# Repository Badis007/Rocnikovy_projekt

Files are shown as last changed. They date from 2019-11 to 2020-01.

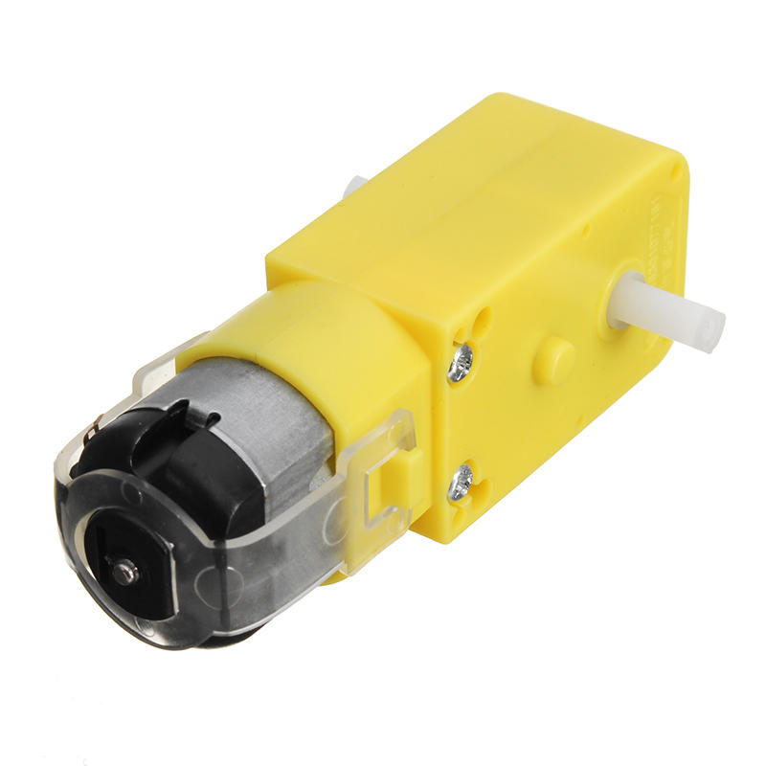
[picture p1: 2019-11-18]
Soucastky/3ec6e260-2719-4dba-aa2e-fc9864818fe9.jpeg

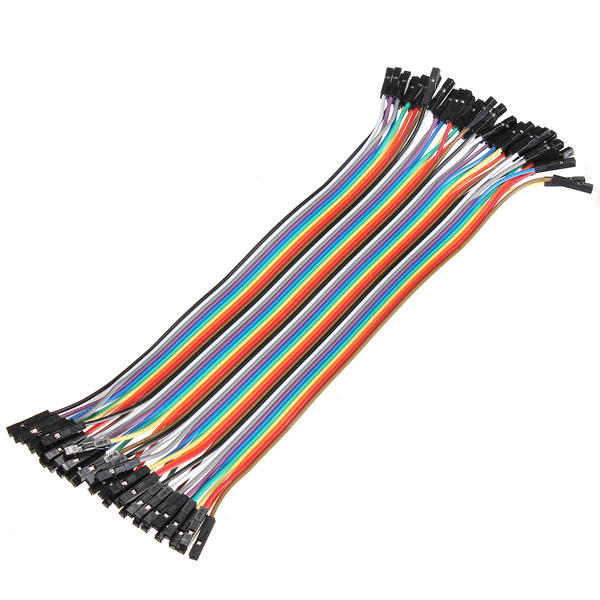
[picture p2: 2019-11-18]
Soucastky/SKU067911h.jpeg

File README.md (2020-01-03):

# Ročníkový projekt - autíčko ovládané přes wifi

Inspirace - https://www.youtube.com/watch?v=mJEftoeSBOU

tohle -> https://www.youtube.com/watch?v=gU7vlhU1HvU

# Harmonogram:
- [x] Září - objednávka součástek

- [x] Říjen - Pájení motorů, stavba podvozku

- [x] Listopad - aplikace, připojení na wifi, zapojení součástek na podvozek.

- [x] Prosinec - zpracování dokumentace.

- [ ] Leden - dokončení a doladění projektu.

# Stav projektu:
- Objednaný podvozek byl moc malý, náhrada dřevěným výřezem. 
- Sestavení autíčka doma bez podvozku, následné rozebrání pro přenos do školy, o víkendu následné sestavení na nový podvozek a nalepení     tavící pistolí. 
- vyřešení připojení na wifi.
- Sestavení celého auta do funkčního stavu.
- Úspěšně otestováno v přiloženém videu na mém githubu ve složce "stavba projektu". 
- V následujících dnech doupravím zapojení auta k lepší vizuální podobě a optimalizuju kód.
- Optimalizovaný kód, z aplikace uložena hodnota 1-5 pro každou funkci zvlášť do stringu, string se v ESP převede na int, poté je poslán      do switche pro splnění podmínek, následně vyvolána určitá funkce podle směru zmáčknutí tlačítka v aplikaci.
- Kabely FM to FM nahrazeny za napájené spoje, přidán vypínač pro lepší přehlednost a vyhnutí se stálemu vytahování baterek z holderu. 
- Kabely motorů vylepšeny a nahrazeny.
- Optimalizovaný kód auta.
- Doladění aplikace, jednoduchž design.
------------------------------------------
- Dokumentace, napájet kolo z5, přilepit motor, test, prezentace

# Potřebné součástky
- 4x motorek + kolečka
- motor driver
- ESP8266
- battery holder 
- přepínač

# Odkazy: 
- ESP8266 https://navody.arduino-shop.cz/navody-k-produktum/esp8266-vyvojova-deska-wemos-d1.html
- L298N https://robotelektro.cz/moduly-sestavene?product_id=81
- Motor s převodovkou https://www.hwkitchen.cz/motor-s-prevodovkou-pro-arduino-robota/

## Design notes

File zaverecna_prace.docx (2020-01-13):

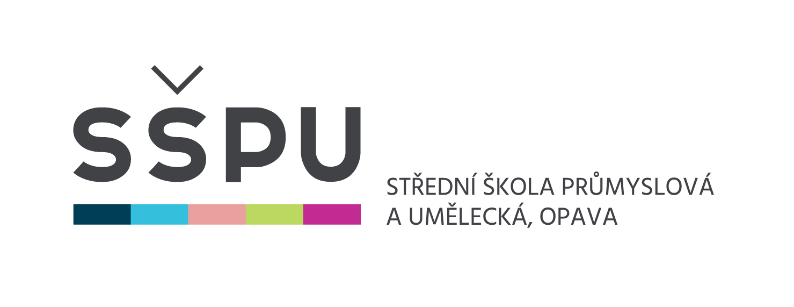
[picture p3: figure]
Logo__SSPU_2016_Barva

Závěrečná studijní práce

dokumentace

Auto na dálkové ovládání

Lukáš Baďura

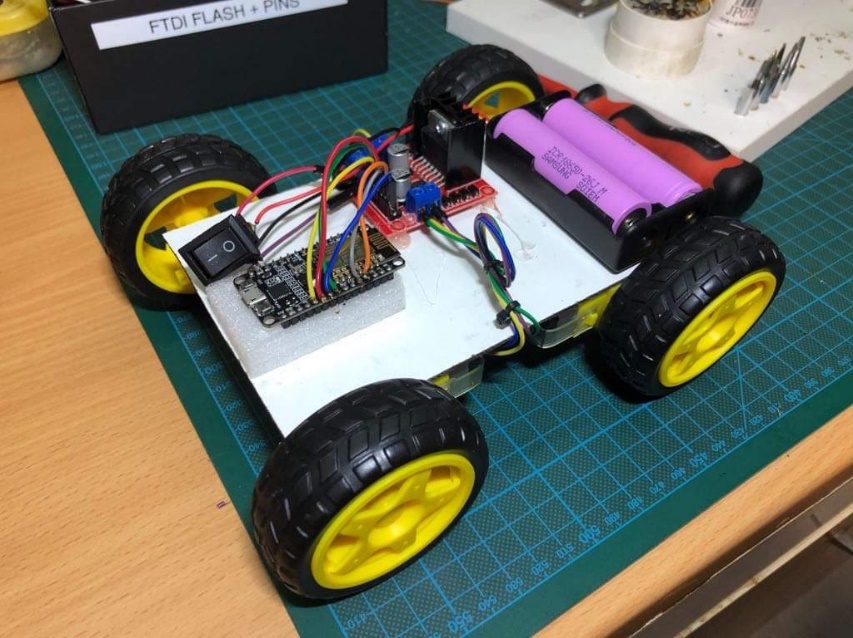
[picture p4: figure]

Obor: | 18-20-M/01 INFORMAČNÍ TECHNOLOGIE se zaměřením na počítačové sítě a programování
Třída: Školní rok: | IT4 2019/2020

#### Poděkování

Děkuji panu učiteli Ing. Petru Grussmannovi za užitečné rady, vylepšení a konzultaci mého projektu. Mým spolužákům za pomoc a řešení společných problémů.

Prohlašuji, že jsem závěrečnou práci vypracoval samostatně a uvedl veškeré použité
informační zdroje.

Souhlasím, aby tato studijní práce byla použita k výukovým účelům na Střední průmyslové
a umělecké škole v Opavě, Praskova 399/8.

V Opavě 31. 12. 2019

podpis autora práce

ANOTACE

Cílem projektu bylo sestavení auta na dálkové ovládání z mobilní aplikace v Android Studiu pomocí WiFi. Hardwarovou část tvoří vývojová deska NodeMcu s čipem ESP8266. Zařízení za pomoci již zmíněného ESP8266 a modulu L298N řídí čtyři převodové motory. Mobilní aplikace posílá ESP hodnoty, pokud jsou vyhodnoceny jako „pravda“ je spuštěna příslušná funkce pro pohyb auta. Softwarová část auta je řešena v jazyce Arduino, který je kombinací jazyků C a C++.

Goal of the project was build a remote controlling car with mobile application in Android Studio which uses WiFi to communicate. Hardware part of the project is development board with chip ESP8266. Project uses ESP8266 and L298N module to control 4 geared motors. Mobile application sends values to ESP. If is value evaluated as „true“ the function for car direction controll is launched. Software part of the project is wrote in Arduino language which is the combination of C and C++ languages.

Klíčová slova

WiFi; dálkové ovládání; NodeMcu; Arduino; převodové motory; mobilní aplikace; motorový modul

# OBSAH

# Úvod

Tento projekt jsem si vybral, aby mi závěrečná práce nebyla nejen znalostním přínosem, ale i zábavou.

Auto na dálkové ovládání mě zaujalo a vybral jsem si ho, po shlédnutí mnoha videí spojených s roboty a auty ovládanými přes WiFi.

Projekt má dvě hlavní části. Ručně sestavené auto na dálkové ovládání a mobilní aplikaci. Tyto dvě části vzájemně komunikují pomocí již zmíněné WiFi. Ve své dokumentaci popisuji použité technologie a principy fungování.

# 1 SESTAVENÍ AUTA

Po zakoupení součástek jsem začal se zapojením jednoho motorku s kolem do jednoduchého obvodu s ESP8266, H-můstkem L298N a externím napájením.

Nahrál jsem do obvodu jednoduchý program pro roztočení kola s motorkem vpřed. Po úspěšném testu součástek jsem se rozhodl na každý motorek s kolem připájet dva drátky a následně přilepit tavnou pistolí ke spodní části podvozku.

Dále jsem na vrchní část podvozku nalepil postupně ESP8266, H-můstek L298N a externí zdroj napájení. Motorky jsem pomocí připájených drátků zapojil do výstupních konektorů H-můstku. H-můstek jsem propojil kabely s ESP a následně zapojil externí napájení. Po zapojení obvodů již na podvozku jsem přešel k nahrání jednoduchého kódu pro pohyb auta vpřed a vzad.

Po úspěšném otestování jsem přešel k finálnímu doladění celého obvodu. Drátky z H-můstku jsem připájel na piny ESP pro bezpečnější funkčnost při jízdě, k externímu napájení jsem přidal vypínač pro pohodlnější zapnutí a drátky vedoucí z motorků jsem lépe spojil k sobě, pro lepší stabilitu a funkčnost auta. Po uspokojivém zapojení všech součástek jsem přešel k řešení problematiky softwarové části.

# 2 Využité technologie

## 2.1 Hardware

### 2.1.1 Seznam součástek

### Vývojová deska NodeMcu

### H-můstek pro krokový motor L298N

### Dvě 18650 Li-Ion Baterie

### Bateriový box

### Propojovací kabely F-F

### Propojovací kabely M-M

### Čtyři kola s převodovými motory

### Přepínač 6A 250VAC

### 2.1.2 NodeMcu

Základ projektu tvoří vývojová deska NodeMcu. Deska je založena na čipu ESP8266 od společnosti Expressif. Hardware je založen na modulu ESP-12E.

Deska obsahuje 11 digitálních I/O pinů a 1 analogový vstup. Programu je k dispozici paměť o velikosti 128kB. NodeMcu na rozdíl od ostatních součástek pracuje s napětím 3,3V.

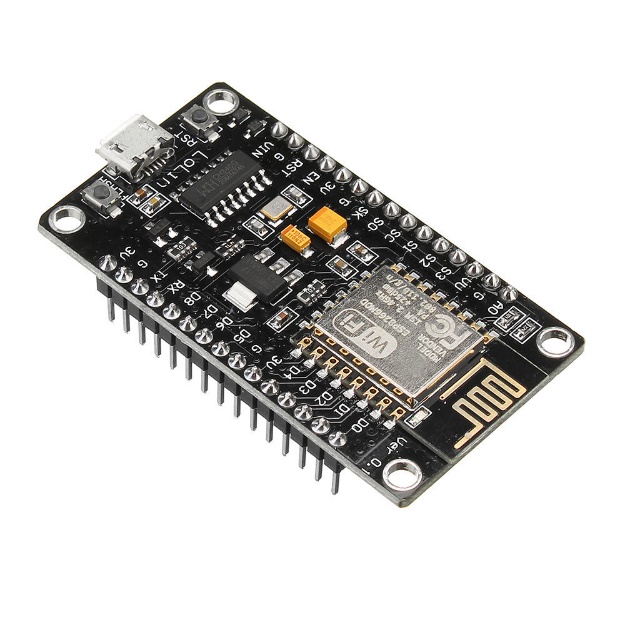
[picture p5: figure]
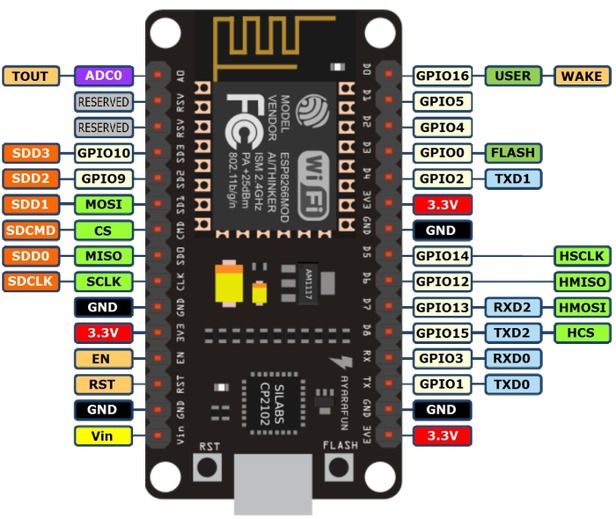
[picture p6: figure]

### 2.1.3 H-můstek L298N

Tento modul používá ST L298N čip. Čip disponuje dobrou schopností řízení, nízkou teplotou a silnými anti-interferenčními schopnostmi.

Slouží k řízení krokových motorů, nebo jako v mém případě převodových motorů. Dá se napájet až do 46V.

Výstupní konektory pro zapojení motorů jsou po stranách označeny jako OUT1, OUT2, OUT3 a OUT4. Dále modul disponuje piny ENABLE A a ENABLE B, které slouží pro aktivaci motorů zapojených do již zmíněných výstupních konektorů. Piny IN1, IN2, IN3 a IN4 slouží pro řízení motorů. Na modulu se nachází 12V silové napájení pro motory, 5V napájení logiky modulu a GND uzemnění.

b13ad2c13e5c1ab897bafda0788c8802

## 2.2 Software

### 2.2.1 Visual Studio Code

Jako vývojové prostředí pro můj projekt, jsem zvolil Visual Studio Code. Prostředí jsem si vybral z důvodu, protože jsem s ním již měl drobné zkušenosti, je vizuálně hezké, přehledné a hlavně je zde možnost použití rozšíření Platformio, které je nezbytné pro můj projekt a velice usnadňuje práci.

### 2.2.2 App Inventor

Jako vývojové prostředí pro moji mobilní aplikaci jsem si zvolil grafický programovací jazyk App Inventor.

V jazyce se dají vyvíjet plnohodnotné aplikace, a jelikož jazyk podporuje operační systém Android, na kterém funguje můj mobilní telefon byl ideální volbou.

# 3 ZPŮSOBY ŘEŠENÍ A POUŽITÉ POSTUPY

## 3.1 Schéma

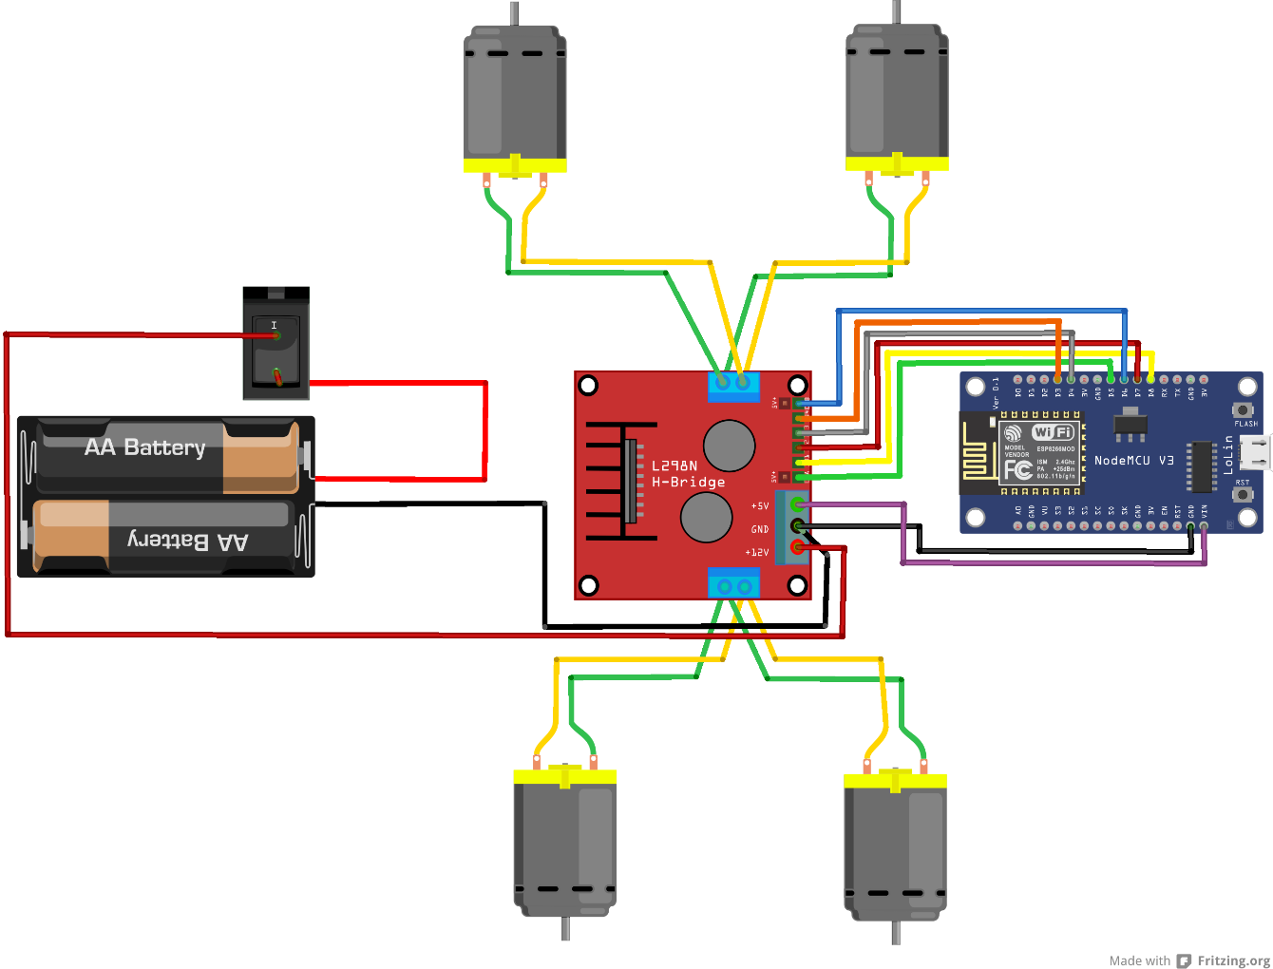
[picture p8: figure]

Schéma jsem vytvořil v programu Fritzing. Program je open-source systém, který umožňuje v jednoduchém rozhraní graficky sestavit zapojení všech komponentů. Fritzing jsem zvolil, protože je velice přehledný, jednoduchý a splňuje veškeré požadavky, které jsem potřeboval. Výsledné schéma je díky grafickému zpracování velmi jednoduché k pochopení.

## 3.2 Použité knihovny

### 3.2.1 ESP8266WiFi.h

Knihovna pro připojení ESP8266 modulu k WiFi. Pro lepší představu níže přikládám výstřižek z mého kódu.

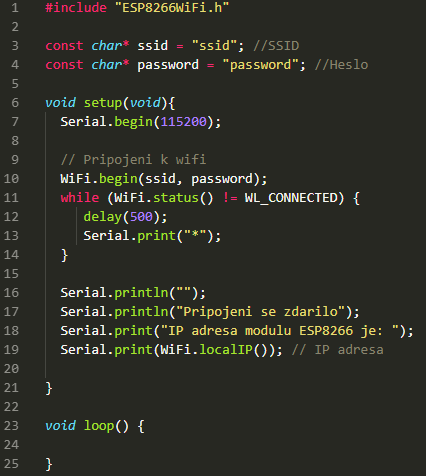
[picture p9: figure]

### 3.2.2 WifiClient.h

Tato knihovna umožňuje vývojové desce připojení k internetu. Může sloužit jako server přijímající příchozí připojení nebo jako klient pro odchozí. Knihovna podporuje šifrování WEP a WPA2 Personal, nikoli však WPA2 Enterprise.

### 3.2.3 ESP8266WebServer.h

Knihovna nutná pro práci s web serverem na našem čipu ESP8266. Knihovna ví jak zpracovat požadavky http, jako je GET a POST. Také dokáže podporovat pouze jednoho klienta. Níže přikládám krátký výňatek z mého kódu, kde spouštím web server.

# 4 HARDWAROVÉ ZAŘÍZENÍ

### 4.1.1 Popis fungování ovládání auta

Auto je ovládáno mobilní aplikací napsanou v jazyce Scratch.

Zde je příklad tlačítka sloužící pro pohyb auta vpřed. Celý blok funguje následovně, pokud je ztisknutý symbol šipky vpřed v mobilní aplikaci, tak se do ESP pošle hodnota “/?State=1“.

Následně hodnota pokračuje do funkce v ESP, která zjistí, jestli přišel parametr “State”. Pokud parametr opravdu přišel, uloží se parametr “State” do proměnné číslo, která je intové hodnoty, protože parametr “State”, který je mimo jiné strinogové hodnoty, je funkcí toInt(); převeden do hodnoty intové, aby mohl být snadněji a přehledněji porovnán.

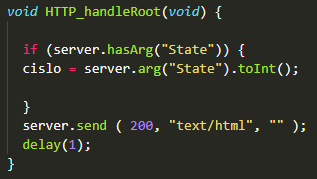
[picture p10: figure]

Když je toto všechno splněno, hodnota uložená v proměnné číslo, je poslána do cyklu switch.

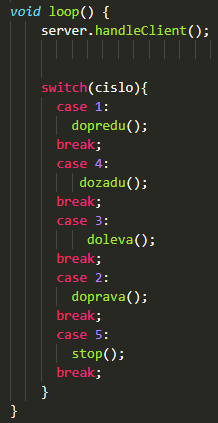
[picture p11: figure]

Každá šipka v aplikaci posílá jinou hodnotu od 1 do 5. Podle toho switch rozpozná, jakou funkci pohybu má následně vyvolat.

Hodnota 1 pro zmíněnou funkci forward je vyhodnocena switchem, jako pravda a je vyvolána funkce “dopredu”.

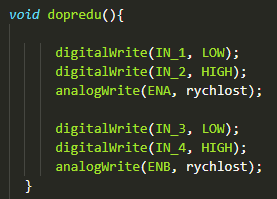
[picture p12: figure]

Funkce “Dopredu ” sepne na určitých pinech a rozpohybuje kola daným směrem. Proměnná rychlost je zde nastavena pevně na hodnotu 800. Tenhle proces se opakuje stále dokola, při stisknutí tlačítek v mobilní aplikaci.

### 4.1.2 Připojení k WiFi

V následující kapitole jsem popsal principy fungování a postupy připojení mého ESP8266 k WiFi síti.

ESP8266 je schopno díky knihovnám vysílat vlastní WiFi, kterou mám uloženou v konstatní proměnné ssid s názvem “Auticko”.

Po nahrání programu do auta, se na sériové lince vypíše IP Adresa ESP, díky následujícím příkazům, které do proměnné mojeIP uloží skutečnou IP Adresu ESP a následně je příkazem vypsána na sériové lince.

Zapojení WebServeru je řešeno následnými třemi jednoduchými příkazy.

### 4.1.3 Převod stringových hodnot z aplikace

V mojí mobilní aplikaci je každé jednotlivé tlačítko pro pohyb auta uloženo a posíla do ESP jinou hodnotu. Hodnoty jsou uloženy ve stringových proměnných “State”.

Když ESP otestuje podmínkou že opravdu přijalo hodnotu “State”, je hodnota následně převedena funkcí toInt(); na hodnotu číselnou a uložena do proměnné číslo.

Proměnná číslo se dále porovná v cyklu switch a vyvolá se daná funkce pro pohyb auta ve správném směru.

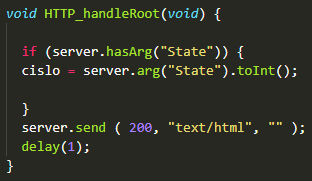
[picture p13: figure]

## 4.1 Mobilní aplikace

Mobilní aplikaci jsem psal ve vývojovém prostředí App Inventro v jazyce Scratch. Tento jazyk s prostředím jsem zvolil, díky nedostačujícím znalostem Javy, jednoduchosti, přehlednosti jazyku a celkovému doporučení všech podobných githubových projektů.

Aplikace je poměrně jednoduchá, jak po zdrojové stránce, tak i po stránce grafické.

Zdrojová struktura aplikace se skládá z několika bloků pro pohyb danými směry, konkrétně se jedná o tlačítka dopředu, dozadu, vlevo, vpravo a tlačítko stop. Všechny tlačítka fungují na stejném principu.

Pokud je stisknutá šipka na obrazovce telefonu, aplikace pošle do ESP hodnotu, se kterou se dále pracuje v programu pro ESP.

Každé tlačítko je doplněno také o hodnotu, která se odešle při spuštění tlačítka, aby auto zastavilo a na jedno stisknutí nepokračovalo dále ve své trase.

Grafická část je velmi jednoduše tvořena čtyřmi šipkami a tlačítkem stop, které byly tvořeny programem Gimp. Aplikace je doplněna o logo školy a tabulku, kde je od základu vepsaná IP Adresa ESP.

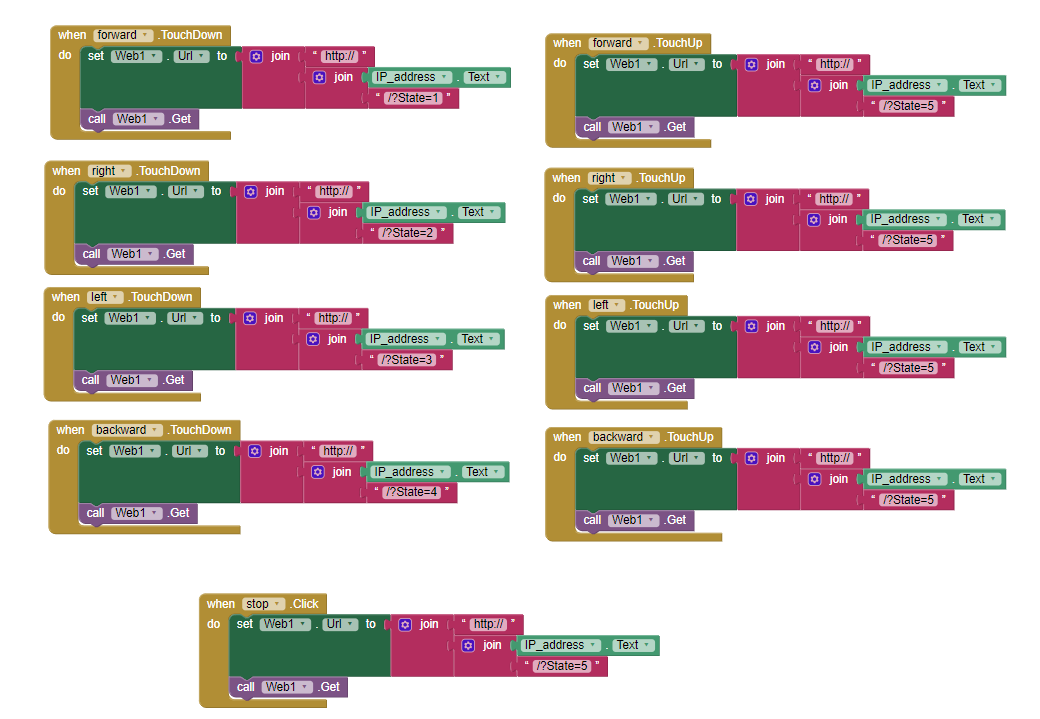
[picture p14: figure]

# 5 VÝSLEDKY ŘEŠENÍ

## 5.1 Podoba zařízení

S autem jsem vcelku spokojen, do budoucna bych chtěl přidat senzor proti naražení do překážky a karosérii pro lepší vzhled. Prozatím auto mé očekávání splňuje a je plně funkční, což bylo hlavním cílem mého projektu.

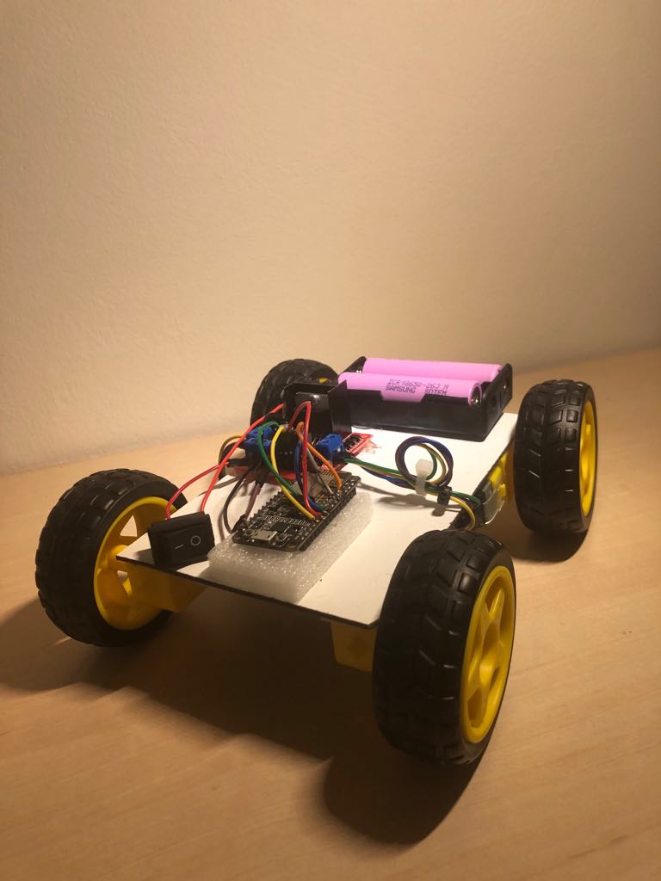
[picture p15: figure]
82121170_476937553254708_2626849315888300032_n

## 5.2 Podoba mobilní aplikace

Mobilní aplikace splňuje svůj účel. Je velmi jednoduchá a naprosto dostačující pro běžného uživatele. Do budoucna bych rád aplikaci vylepšil o akceleraci, lepší grafické zpracování a přidání bočních směrů, aby nebylo nutné mačkat dvě šipky najednou.

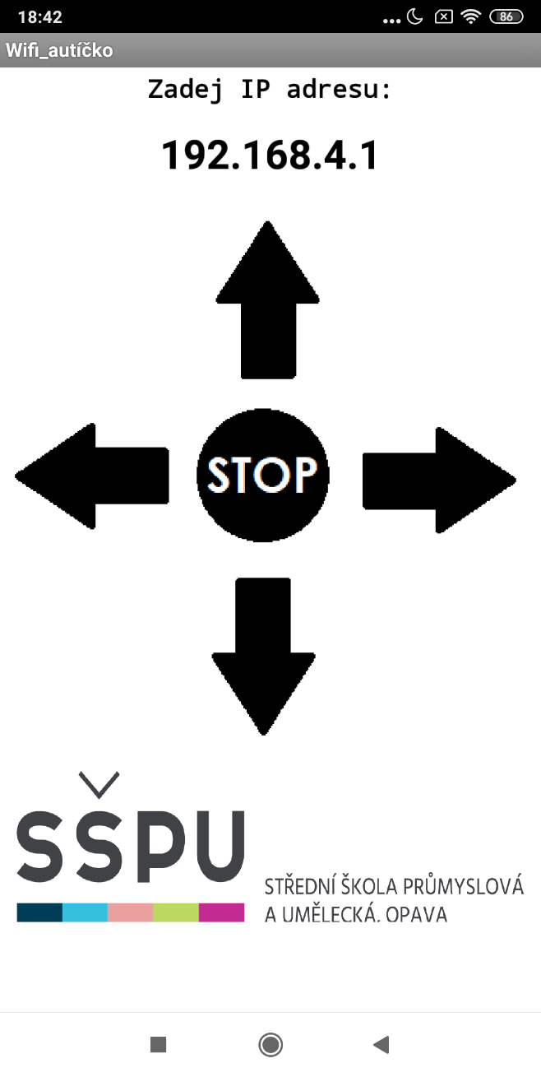
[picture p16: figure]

## 5.3 Problémy

Při tvorbě svého projektu jsem se nepotýkal s mnoha problémy.

Pár jich však nastalo ze začátku díky chybnému připájení, se levé přední kolo točilo opačným směrem, než mělo. Tím samozřejmě brzdilo chod celého auta, jako celku.

Při programování ESP se mi mnoho problému nenaskytlo, protože můj kód je vcelku jednoduchý a funkční. Chvíli jsem bojoval s myšlenkou, jak dostat hodnoty do switche a celé převést. Vymýšlel jsem zbytečně složité věci, když řešení bylo velmi jednoduché.

Velký problém pro mě byla aplikace. Při představě, že se budu muset naučit Javu tak, abych byl schopen naprogramovat aplikaci pro řízení směru, která komunikuje s WiFI.

Po mnoha pokusech, přečtení mnoha githubových projektů, jsem dospěl k závěru, že snazší a efektivnější bude zvolit Scratch.

Při dokončování projektu jsem se potýkal již jen s banalitami, hlavně při přenášení do školy, které způsobilo neustále závady ne mém projektu, díky čemuž jsem byl nucen objednat nový motorek, napájet drátky několikrát znovu a mnoho dalšího.

# Závěr

Můj projekt splnil vše, co jsem od něj očekával. Bohužel mé očekávání nepředčil a nebyl jsem schopen splnit některé cíle. Do budoucna bych určitě rád zapracoval na svých znalostech, abych mohl podobné projekty postavit a vylepšit bez větších problémů.

Projekt mi byl přínosem, lépe jsem pochopil některé principy, fungování a celkově mi rozšířil obzory. Projekt po svém odprezentování věnuji mladšímu bratrovi jako hračku, protože to je zatím jeho jediné využití.

# Seznam použitýCH INFORMAČNÍCH ZDROJů

[1] LASKARDUINO.cz [online]. eshop [cit. 2020-01-13]. Dostupné z: https://www.laskarduino.cz/. Závěrečný projekt. SŠPU Opava. Vedoucí práce Ing. Petr Grussmann.

[2] Github: social network [online]. [cit. 2020-01-13]. Dostupné z: https://github.com/. Závěrečný projekt. SŠPU Opava. Vedoucí práce Ing. Petr Grussmann.

[3] Arduino: community forum [online]. [cit. 2020-01-13]. Dostupné z: https://forum.arduino.cc/. Závěrečný projekt. SŠPU Opava. Vedoucí práce Ing. Petr Grussmann.

[4] Návody: Arduino [online]. [cit. 2020-01-13]. Dostupné z: https://navody.arduino-shop.cz/navody-k-produktum/. Závěrečný projekt. SŠPU Opava. Vedoucí práce Ing. Petr Grussmann.

[5] Youtube: Tutoriály [online]. [cit. 2020-01-13]. Dostupné z: https://www.youtube.com/. Závěrečný projekt. SŠPU Opava. Vedoucí práce Ing. Petr Grussmann.

Fotodokumentace

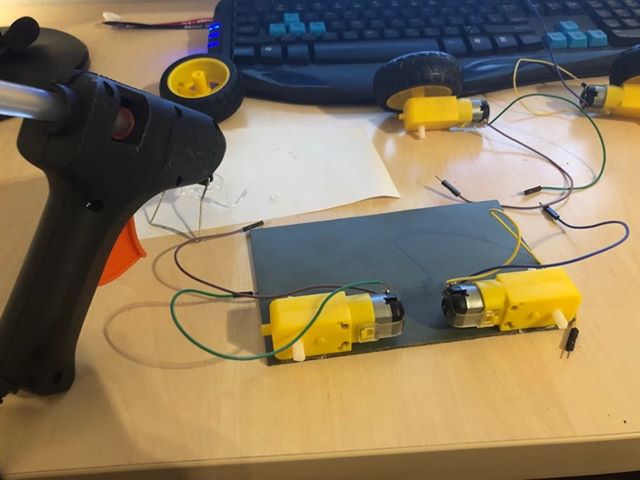
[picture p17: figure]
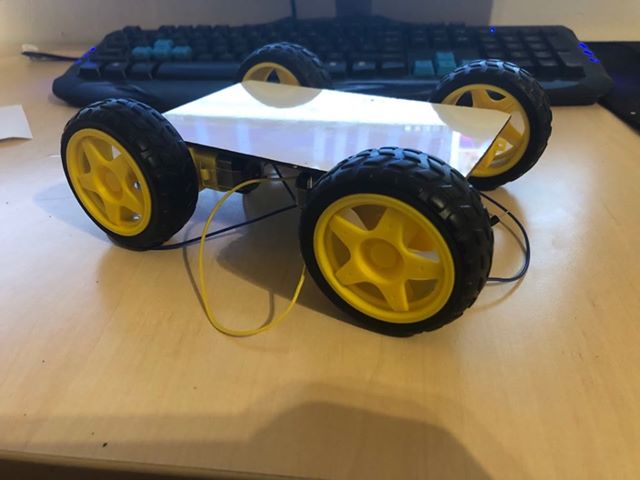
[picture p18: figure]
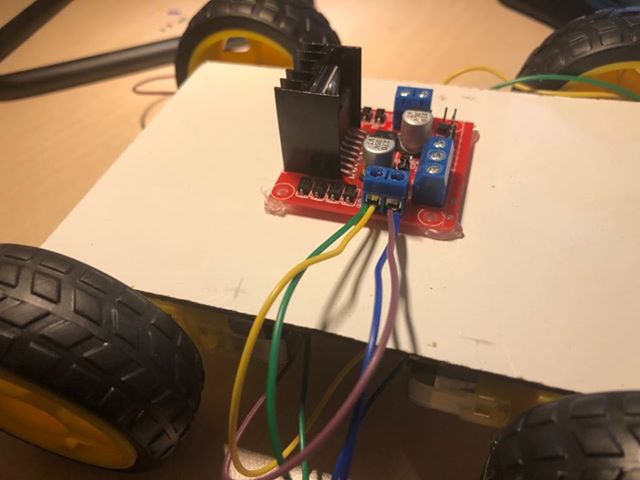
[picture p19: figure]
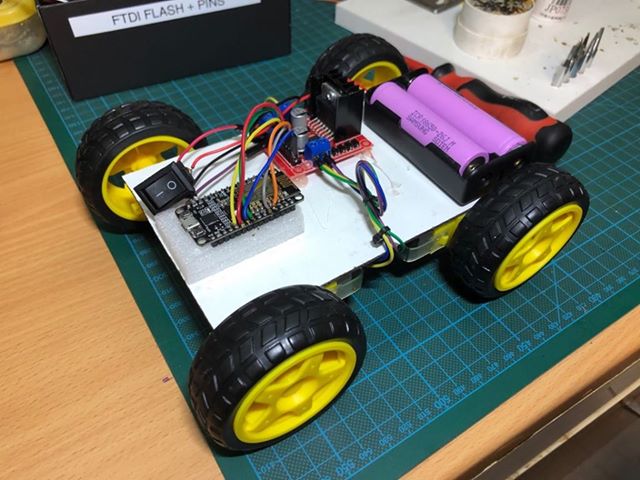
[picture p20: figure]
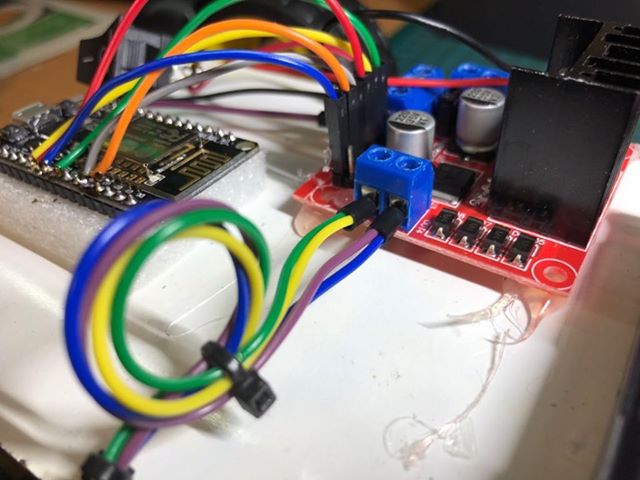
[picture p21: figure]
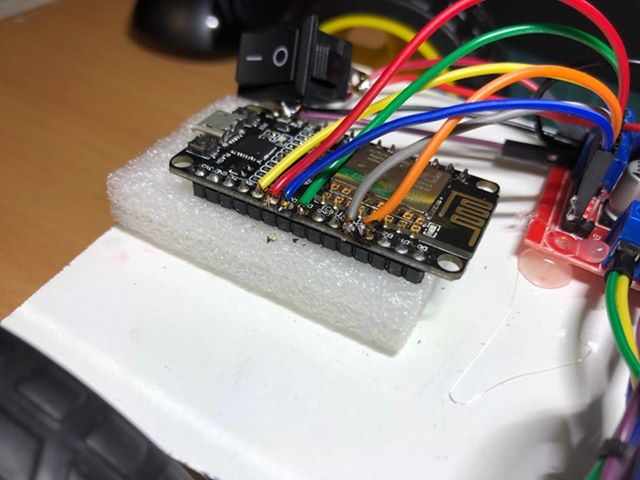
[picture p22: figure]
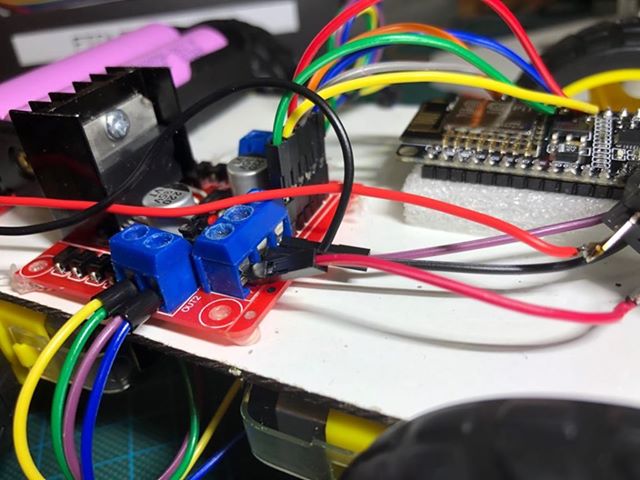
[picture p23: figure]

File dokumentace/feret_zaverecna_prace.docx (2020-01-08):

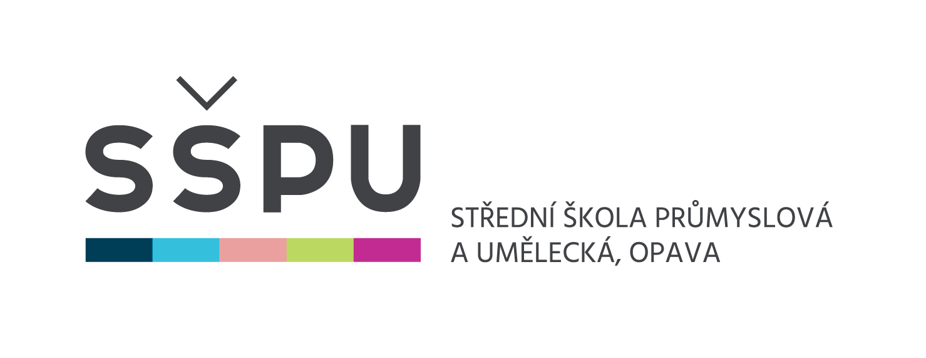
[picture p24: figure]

Závěrečná studijní práce

dokumentace

Bezpečnostní systém se vzdáleným ovládáním

Jakub Feret
Obor: | 18-20-M/01 INFORMAČNÍ TECHNOLOGIE se zaměřením na počítačové sítě a programování
Třída: Školní rok: | IT4 2017/2018

###### Poděkování

Děkuji panu učiteli Ing. Petru Grussmannovi za cenné rady, panu učiteli Mgr. Marcelu Godovskému za pomoc se součástkami a panu učiteli Mgr. Markovi Lučnému za rady a pomoc při nahrání aplikace na školní hosting.

Prohlašuji, že jsem závěrečnou práci vypracoval samostatně a uvedl veškeré použité
informační zdroje.

Souhlasím, aby tato studijní práce byla použita k výukovým účelům na Střední průmyslové
a umělecké škole v Opavě, Praskova 399/8.

V Opavě 31. 12. 2017

podpis autora práce

Anotace

Projekt se zabývá tvorbou bezpečnostního systému s možností bezdrátového ovládání přes WiFi. Skládá se z hardwarové a softwarové části. Základ hardwarové části tvoří hlavně vývojová deska NodeMcu. Zařízení pomocí ultrazvukového senzoru snímá vzdálenost k nejbližší překážce, a pokud se tato vzdálenost změní, spustí se program. Ten po uplynutí aktivační doby upozorní uživatele SMS zprávou na možné narušení bezpečnosti. Zařízení lze aktivovat i deaktivovat zadáním hesla z klávesnice, popřípadě pomocí webové aplikace. Programová část bezpečnostního systému je řešena v jazyce Arduino, což je kombinace jazyků C a C++. Druhou část projektu tvoří webová aplikace vyvinutá v jazyce PHP s využitím Nette Frameworku. Tato aplikace umožňuje po přihlášení vzdáleně ovládat bezpečnostní zařízení. Administrátor může kromě aktivace nebo deaktivace alarmu také upravovat časové prodlevy před aktivací nebo spravovat uživatelské účty.

Klíčová slova

Bezpečnost; NodeMcu; ESP8266; Nette; WiFi; bezdrátová komunikace; webová aplikace; Arduino; PHP

# OBSAH

# Úvod

Rozhodl jsem se vytvořit bezpečnostní systém se vzdáleným ovládáním prostřednictvím webové aplikace, protože mi problematika Internetu věcí, tedy propojení hardwarových zařízení s Internetem, připadala velmi zajímavá a sám jsem si chtěl něco takového vyzkoušet. Na podobném principu jako můj bezpečnostní systém totiž může fungovat například ovládání celých chytrých domácností, kde je možné třeba z mobilního telefonu zapnout světla, nebo postavit na čaj. Bezpečnostní systém upozorní uživatele SMS zprávou, světelným a zvukovým signálem na pohyb před senzorem. Zařízení lze využít ke kontrole nemovitostí či osobních předmětů.

Hlavním cílem projektu však bylo propojit zařízení se zabezpečenou webovou aplikací a umožnit tím jeho vzdálené ovládání. Uživatel se k aplikaci připojí pomocí uživatelského jména a hesla. Běžní uživatelé pak mohou systém bezpečně aktivovat nebo deaktivovat. Administrátor má navíc možnost změnit v aplikaci dobu do aktivace a do spuštění alarmu. Zároveň může vytvářet nové uživatelské účty, popřípadě upravovat nebo mazat současné.

Protože se jednalo o můj první projekt v této oblasti, zvolil jsem pro jeho realizace známé a dobře zdokumentované technologie. S některými z nich, jako například s Nette Frameworkem, jsem se již setkal ve škole. Hardwarovou část tvoří hlavně vývojová deska NodeMcu s WiFi modulem ESP8266 a k němu připojené další komponenty, o kterých se ještě zmíním v dalších částech dokumentace. Bezpečnostní zařízení je naprogramováno v jazyce Arduino, jedná se o kombinaci jazyků C a C++. Webovou aplikaci řeším pomocí PHP frameworku Nette. Komunikace mezi aplikací a bezpečnostním zařízením probíhá přes WiFi na principu REST API.

V této dokumentaci podrobně popisuji výrobu bezpečnostního systému a princip jeho fungování. Na začátku se zmiňuji o problémech, se kterými jsem se setkal při vývoji bezpečnostního zařízení, pokračuji popisem technologií nezbytných k jeho výrobě i k jeho současné funkčnosti a rozebírám, jak funguje nejen samotné bezpečnostní zařízení, ale i webová aplikace potřebná k jeho vzdálenému ovládání. V další části vysvětluji, na jakých principech funguje jejich vzájemná komunikace, a popisuji jednotlivé úkony obou částí systému. V závěru se zabývám současnou podobou bezpečnostního systému a hodnotím odvedenou práci.

# 1 Výroba bezpečnostního systému

První část mého projektu představovalo sestavení samotného zařízení. Protože se jednalo o mou první zkušenost se sestavováním integrovaných obvodů, výběru a nákupu součástek předcházel zdlouhavý výzkum dané problematiky. Nejdříve jsem se rozhodl jako základ mého zařízení použít vývojovou desku Arduino UNO, založenou na mikrokontroléru ATmega328 od firmy Atmel. Pro komunikaci s webovou aplikací jsem vybral WiFi modul ESP8266-01. Toto spojení se však časem ukázalo jako nepraktické a neefektivní, proto jsem se rozhodl nahradit jak Arduino UNO, tak ESP8266-01 vývojovou deskou NodeMcu, která již obsahuje WiFi modul ESP8266.

Vzhledem k tomu, že jsem s nakoupenými součástkami nikdy dříve nepracoval, rozhodl jsem se postupovat po malých krocích. Zapojoval jsem jednu součástku po druhé do nepájivého pole a hned jsem zkoušel její funkčnost pomocí jednoduchých příkladů v Arduino IDE. Finální verzi projektu jsem nejdříve navrhl v programu Fritzing, kde jsem si odzkoušel rozvržení součástek na nepájivém poli.

Po zapojení a odzkoušení všech součástek jsem přešel k programování samotného bezpečnostního systému. Pro tento účel jsem zvolil programovací jazyk přímo pro Arduino, což je kombinace jazyků C a C++. Když byla první část projektu plně funkční, čekala mě ta pravá výzva – spojit zařízení přes WiFi s webovou aplikací a umožnit tak jeho ovládání na dálku, což byl, jak jsem již zmiňoval, hlavní cíl mého projektu.

Webovou aplikaci jsem se rozhodl vyřešit pomocí PHP frameworku Nette, se kterým jsem již měl zkušenost ze školy, spolu s databázovým systémem MySQL. Protože se jedná o aplikaci určenou pro ovládání bezpečnostního systému, snažil jsem se ji co nejvíce zabezpečit. Každý uživatel aplikace se musí nejprve přihlásit svým uživatelským jménem a heslem. Administrátor pak může vytvářet, upravovat či mazat uživatele a má také plnou kontrolu nad samotným bezpečnostním zařízením – může měnit intervaly před aktivací a před spuštěním alarmu a samozřejmě také zařízení na dálku zapnout nebo vypnout. Ostatní uživatelé pak mají možnost změnit pouze vlastní přihlašovací údaje a také mohou zapnout nebo vypnout alarm.

# 2 Princip fungování vzdáleného ovládání

Propojení ESP8266 a webové aplikace jsem nejdříve řešil tak, že jsem v aplikaci měnil hodnoty v MySQL databázi a k nim jsem pak přistupoval z ESP8266 pomocí knihovny MySQL Connector. To se ukázalo jako nevyhovující, jednak kvůli bezpečnosti a také kvůli tomu, že by toto řešení spolehlivě fungovalo pouze na lokální úrovni.

Rozhodl jsem se raději vytvořit jednoduché REST API. V aplikaci vypisuji hodnoty do JSON výstupu a k tomu přistupuji z ESP8266 pomocí HTTP GET požadavku. Přijatá data pak pomocí knihovny ArduinoJson dekóduji a ukládám do proměnných, se kterými pak můžu dále pracovat. Díky tomu jsem schopen alarm na dálku zapnout, popřípadě změnit jeho nastavení. Bylo však také potřeba zajistit, aby se server dozvěděl o případném manuálním vypnutí alarmu z klávesnice a změnil pak příslušnou hodnotu v databázi. Tento problém jsem vyřešil pomocí požadavku POST. Opět vytvářím JSON výstup, tentokrát ho však posílám do Nette webové aplikace, kde ho dekóduji a ukládám do databáze. Ani tento postup však není příliš vhodný, zejména kvůli potřebě posílat v pravidelných intervalech požadavky na server (například každých deset vteřin, nejlépe ještě častěji) a zjišťovat, zda se hodnoty nezměnily. To vede k velkému odběru elektrické energie, což mi znemožňuje napájet zařízení z baterie, jak jsem původně plánoval.

To by bylo možné, pokud bych zařízení propojil se serverem bez nutnosti posílat na něj každou chvíli požadavky. Mohl bych tak uvést zařízení do režimu spánku, dokud by nedostalo impuls k probuzení, například změněním určité hodnoty. Tím bych výrazně snížil spotřebu elektrické energie. Chtěl jsem proto opět změnit princip komunikace mezi webovou aplikací a ESP8266, konkrétně jsem měl v plánu použít komunikační protokol MQTT, který umožňuje propojení se serverem bez nutnosti neustálého posílání požadavků. Protože však Nette MQTT nijak nepodporuje, bylo by nutné kompletně přepsat webovou aplikaci, nejlépe do jiného jazyka (například Pythonu), což by se mi bohužel nepodařilo stihnout před termínem odevzdání projektu, a tak jsem zařízení ponechal v současném funkčním, avšak ne zcela vyhovujícím stavu.

# 3 Využité technologie

## 3.1 Hardware

### 3.1.1 Seznam součástek

- Vývojová deska NodeMcu,
- ultrazvukový senzor HC-SR04,
- LCD displej 1602,
- LCD I2C sériové rozhraní
- membránová klávesnice 4x4,
- I2C sběrnice PCF8574P,
- 5 V bzučák,
- červená LED,
- rezistor 330 Ω,
- obousměrný osmi-kanálový převodník logických úrovní,
- napájecí modul nepájivého pole,
- 2 nepájivé pole se 400 kontakty.

### 3.1.2 NodeMcu

Základ projektu tvoří vývojová deska NodeMcu (obrázek č. 1). Firmware obstarává WiFi modul ESP8266 od společnosti Espressif Systems, hardware je založen na modulu ESP-12E, ovšem s šesti GPIO piny navíc. NodeMcu tedy obsahuje 12 digitálních GPIO pinů a jeden analogový pin (obrázek č. 2). Pro program je k dispozici paměť o velikosti 128 kB. Na rozdíl od většiny ostatních komponentů, NodeMcu pracuje s napětím 3,3 V.

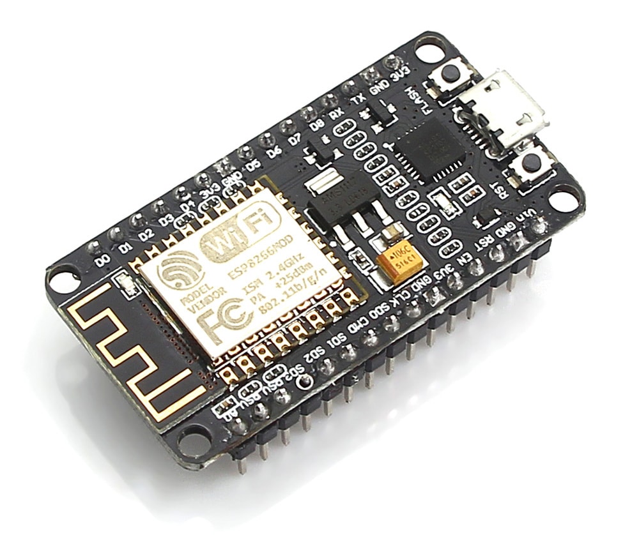
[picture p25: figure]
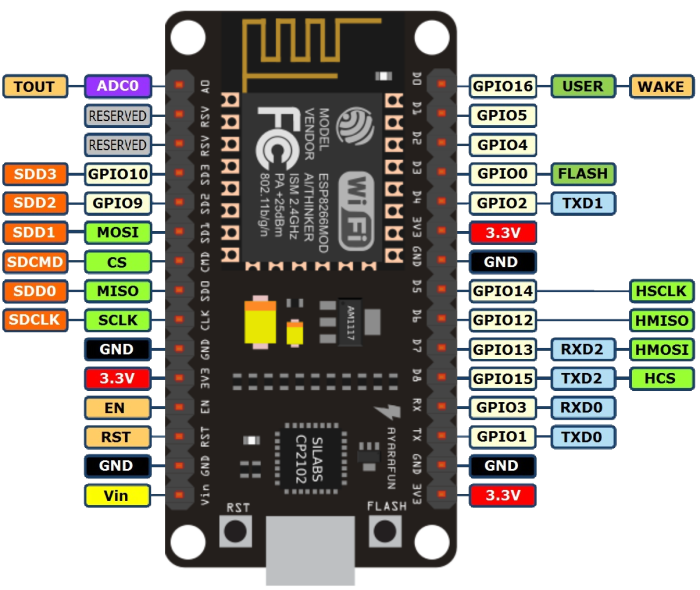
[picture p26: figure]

Obrázek č. 2 Piny NodeMcu

Obrázek č. 1 NodeMcu

### 3.1.3 Ultrazvukový senzor HC-SR04

Bezpečnostní systém funguje na principu ultrazvukových vln, které měří vzdálenost k nejbližší překážce. To zajišťuje ultrazvukový senzor HC-SR04, který je schopný pomocí ultrazvukových vln změřit vzdálenost od dvou do 400 cm s přesností plus mínus tři milimetry. Úhel měření je 15 stupňů. Senzor po aktivaci automaticky pošle osm 40 kHz vln a čeká na odražený signál. Pokud odražený signál dorazí zpět, senzor zaznamená čas od vyslání vlny k jejímu návratu. Vzdálenost se pak vypočítá jako doba od vyslání vlny k jejímu návratu * rychlost zvuku / 2 (obrázek č. 3). Při vymýšlení principu fungování bezpečnostního zařízení jsem se rozhodoval mezi ultrazvukovým senzorem a pohybovým čidlem. Pro ultrazvukový senzor jsem se rozhodl hlavně proto, že pohybové čidlo po spuštění snímá celou místnost a zaznamená jakýkoliv pohyb v dané místnosti. Nehodí se proto do domácností s volně se pohybujícími zvířaty. Ultrazvukový senzor naproti tomu snímá pouze určitou oblast přímo před sebou, takže pokud se nainstaluje na správné místo, je senzor schopen zaznamenat například otevření dveří, avšak zvíře procházející kolem dveří už nezaznamená.


Obrázek č. 3 Funkce pro získání vzdálenosti z ultrazvukového senzoru

### 3.1.4 LCD displej 1602

Jako výstupní zařízení jsem použil LCD displej 1602, který dokáže zobrazit 32 znaků na dvou řádcích (16 x 2). Kvůli omezenému počtu pinů na NodeMcu jsem pro připojení využil I2C sériové rozhraní, které mi umožnilo připojit displej pouze dvěma vodiči. Funkčnost displeje obstarává knihovna LiquidCrystal_I2C.

### 3.1.5 Membránová klávesnice 4x4

Uživatelský vstup řeším pomocí membránové klávesnice o šestnácti klávesách (4 řádky a 4 sloupce). Pro fungování klávesnice je potřeba osm vodičů, pro které jsem však neměl k dispozici dostatek pinů. Nejdříve jsem se proto rozhodl zredukovat osm digitálních pinů na jeden analogový, a to pomocí pole rezistorů. Využil jsem toho, že funkce analogRead() dokáže přiřadit vstupní napětí od 0 do 3,3 V číselným hodnotám od 0 do 1024. Díky rezistorovému poli bude po zmáčknutí každé klávesy tato hodnota vždy jiná. Napsal jsem si tedy jednoduchou knihovnu v jazyce C++, která ke každé hodnotě, kterou získám funkcí analogRead() z analogového pinu, přiřadí danou klávesu. Bohužel po přechodu z Arduino Uno na NodeMcu toto řešení vyústilo v řadu problémů, zejména kvůli nedokonalému vyvedení analogového pinu NodeMcu, na kterém jsem naměřil četné výkyvy signálu způsobující nepředvídatelné chování kláves. Rozhodl jsem se proto vyřešit zapojení klávesnice pomocí I2C sběrnice PCF8574P, podobně jako u LCD displeje.

Protože je díky I2C sběrnici klávesnice připojená ke stejným pinům jako LCD displej, zbývá mi dostatek pinů pro ostatní komponenty. Aby to však bylo možné, nesmí mít LCD displej a klávesnice stejnou I2C adresu. Pomocí jednoduchého Arduino programu jsem zjistil, že displej používá adresu 0x27, stačilo tak nastavit pro klávesnici jakoukoliv jinou adresu, s čímž mi pomohla tabulka na obrázku č. 4. Zvolil jsem adresu 0x21, takže bylo nutné u I2C sběrnice PCF8574P uzemnit piny A2 a A1 a pin A0 připojit k napětí 3,3 V.


Obrázek č. 4 Tabulka pro určení I2C adresy

Funkčnost klávesnice obstarává knihovna Keypad_I2C. Hodnoty kláves se zapisují do dvourozměrného pole (obrázek č. 5).


Obrázek č. 5 Deklarace proměnných pro klávesnici

Dále je potřeba klávesnici inicializovat ve funkci setup() (obrázek č. 6).

Obrázek č. 6 Inicializace klávesnice

Vždy, když je potřeba v nějaké funkci zjišťovat, zda byla stisknuta nějaká klávesa, musí se z knihovny Keypad_I2C zavolat funkce getKey() (obrázek č. 7).

Obrázek č. 7 Zapsání stisknuté klávesy do proměnné keypressed

### 3.1.6 Bzučák a LED

Součástí zařízení je také 5 V bzučák o frekvenci 2,3 kHz, který slouží k upozornění na stisknutí tlačítka a také jako bezpečnostní prvek, který má hlasitým zvukem vylekat případného narušitele. Jako další bezpečnostní prvek slouží červená LED, která po spuštění alarmu začne jasně svítit.

## 3.2 Napájení

Problém nastal při řešení napájení jednotlivých komponentů, zejména proto, že vývojová deska NodeMcu a WiFi modul ESP8266 pracují s jiným napětím, než ostatní součástky. Konkrétně NodeMcu vyžaduje napětí 3,3 V, zatímco ostatní komponenty 5 V. Tento problém jsem se rozhodl vyřešit pomocí obousměrného osmi-kanálového převodníku logických úrovní, který je schopen převádět 5 V na 3,3 V a naopak.

Samotné napájení je řešeno pomocí napájecího modulu nepájivého pole, který dokáže připojit napájení do dvou napěťových větví. U každé z nich lze jumperem zvolit, jaké napětí do ní bude přivedeno (buď 3,3 V, nebo 5 V). Modul vyžaduje vstupní napětí od 6,5 V do 12 V, které lze přivést kabelem z elektrické sítě nebo pomocí USB z počítače. Maximální výstupní proud je 700 mA, což je dostačující pro napájení většiny součástek.

Všechny komponenty jsem připojil na dvě nepájivá pole, každé z nich disponuje 400 kontakty.

## 3.3 Software

### 3.3.1 Jazyk Arduino

Program sloužící k ovládání hardwarových součástek jsem napsal v jazyce Arduino, který je, až na drobné úpravy, velmi podobný jazyku C nebo C++. Jazyk Arduino byl přímo vytvořen k programování integrovaných obvodů.

### 3.3.2 Webová aplikace

Webovou aplikaci jsem řešil v jazyce PHP, konkrétně jsem využil PHP frameworku Nette ve verzi 2.4. Při tvorbě uživatelského rozhraní jsem použil framework Bootstrap v3.3.4, který mi usnadnil práci s HTML5 a CSS, hlavně v oblasti responzibility. Vzhled uživatelského rozhraní jsem řešil pomocí kaskádových stylů CSS3 a také pomocí javascriptové knihovny jQuery. K provozu aplikace využívám databázový systém MySQL, ve kterém ukládám jak uživatelské údaje, tak data nutná pro ovládání samotného bezpečnostního zařízení. Celá aplikace běží na Apache HTTP Serveru.

### 3.3.3 Arduino IDE 1.8.5

Jako vývojové prostředí jsem pro Arduino program zvolil Arduino IDE 1.8.5, které je přímo uzpůsobeno pro nahrávání programů do vývojových desek jako Arduino nebo NodeMcu.

### 3.3.4 NetBeans 8.2

Pro vývoj PHP webové aplikace jsem zvolil integrované vývojové prostředí NetBeans 8.2, kvůli jeho přehlednému uživatelskému rozhraní a jeho podpoře množství programovacích jazyků.

### 3.3.5 XAMPP 5.6.32

Při vývoji webové aplikace byl nezbytný multiplatformní softwarový balíček XAMPP, díky kterému je možné vytvořit lokální webový server. Konkrétně jsem použil verzi 5.6.32. Balíček obsahuje serverovou aplikaci Apache, databázi MariaDB a skriptovací jazyk PHP. XAMPP jsem zvolil kromě jeho jednoduchosti a intuitivního ovládání také proto, že většina webových serverů využívá stejné komponenty jako XAMPP, takže je přechod z lokálního testovacího serveru na živý server velmi jednoduchý.

### 3.3.6 Fritzing 0.9.3b

Pro návrh bezpečnostního zařízení jsem použil open-source program Fritzing ve verzi 0.9.3b. Ten umožňuje graficky sestavit zapojení jednotlivých součástek na nepájivém poli, což pomáhá k lepší představě o výsledném rozložení. Program dále usnadňuje tvorbu schématu zařízení, podle kterého lze pak navrhnout desku plošných spojů, jejíž výrobu je možné přímo v programu objednat.

# 4 Způsoby řešení a použité postupy

## 4.1 Hardwarové zařízení

### 4.1.1 Nahrávání programu

Bezpečnostní zařízení je umístěno v uzavřené krabičce, případná úprava programu přes sériový port je proto značně problematická a v běžném provozu prakticky nemožná. Tento problém jsem vyřešil zprovozněním OTA (over the air) přenosu pomocí knihovny ArduinoOTA, která mi umožňuje nahrát firmware do ESP8266 bezdrátově přes WiFi. Po zapnutí zařízení je vyčleněn čas, ve kterém je možné bezdrátově nahrát nový program (obrázek č. 8) a teprve po uplynutí tohoto času začne bezpečnostní systém pracovat.


Obrázek č. 8 Odpočítávání času, ve kterém je možné bezdrátově nahrát nový firmware

### 4.1.2 Popis fungování bezpečnostního systému

Po zapnutí NodeMcu se automaticky spustí funkce setup(). Ta se připojí k WiFi pomocí knihovny WiFiManager a zavolá funkci loop(), která nejprve na několik vteřin umožní bezdrátově nahrát nový program pomocí OTA (over the air) přenosu (obrázek č. 8), poté vypíše na displej zprávu a zavolá funkci enterPassword(). Po zadání správného hesla se spustí funkce activateAlarm(), která odpočítává čas do aktivace systému. Tento čas slouží k opuštění hlídaného prostoru. Uživatel má zároveň možnost odpočet zrušit, a to stisknutím klávesy C a zadáním správného hesla, čímž se opět zavolá funkce loop(). Po uplynutí času se spustí funkce alarmCheck() (obrázek č. 9), která pomocí funkce getDistance() aktivuje ultrazvukový senzor a začne měřit vzdálenost k nejbližší překážce.


Obrázek č. 9 Ukázka kódu funkce alarmCheck()

Pokud se tato vzdálenost změní, aktivuje se odpočet do spuštění alarmu, pomocí funkce ledBlink() se rozbliká LED a zavolá se funkce enterPassword(), což dává uživateli možnost zadat platné heslo a tím odpočet zrušit. Pokud to neudělá, zavolá se po uplynutí odpočtu funkce alarmActivated(). Ta spustí naplno bzučák a jasně rozsvítí červenou LED. Zároveň se informace o spuštění alarmu odešle na server a webová aplikace zajistí odeslání SMS uživateli. Nakonec se zavolá funkce enterPassword(), ve které lze zadáním správného hesla alarm deaktivovat.

### 4.1.3 Ověření hesla

Stěžejní funkcí programu je funkce enterPassword(). Při tvorbě zařízení pro mě byla bezpečnost systému velmi důležitá, proto musí být naprostá většina požadavků ověřená zadáním hesla. Na začátku se zavolá funkce eepromRead(), která zpřístupní současné platné heslo uložené v EEPROM paměti pro porovnání se zadaným heslem. Pak přijde na řadu funkce temporaryPassword(), jejíž úkolem je číst hodnotu stisknuté klávesy a ukládat ji do proměnné. Po stisknutí klávesy * se ve funkci enterPassword() tato proměnná porovná s platným heslem uloženým v EEPROM paměti. Následující akce se odvíjejí od současné situace alarmu – pokud je alarm vypnutý a je zadáno platné heslo, spustí se funkce pro aktivaci alarmu activateAlarm(). Pokud je alarm již zapnutý a je zadáno platné heslo, zavolá se naopak funkce pro deaktivaci alarmu deactivateAlarm(). Uživatel má také možnost zrušit probíhající odpočet do aktivace alarmu a i v tomto případě funkce enterPassword() zajistí po zadání hesla deaktivaci alarmu. Při pokusu o deaktivaci alarmu před vypršením času do spuštění má uživatel tři pokusy na zadání platného hesla. Pokud se mu to nepodaří, je okamžitě zavolána funkce alarmActivated() a alarm se spustí.

### 4.1.4 Změna hesla

Uživatel má také možnost současné heslo změnit, stará se o to funkce changePassword(). Funkci lze vyvolat, pokud alarm není aktivován, stisknutím klávesy B. Funkce vyžaduje zadání současného a nového hesla. Nové heslo musí mít čtyři až šest čísel a kvůli zamezení případným překlepům je nutné ho zadat dvakrát. Pokud jsou všechny podmínky splněny, zavolá se funkce eepromWrite(), která nové heslo uloží do EEPROM paměti.

### 4.1.5 Připojení k WiFi

Pro snadnější připojení k WiFi jsem využil knihovnu WiFiManager pro ESP8266. Díky ní se zařízení po zapnutí automaticky pokusí o připojení k již nakonfigurované WiFi síti. Pokud se to nepodaří, nebo pokud ještě žádná síť nakonfigurována nebyla, automaticky vytvoří web server, na kterém uživatel zadá heslo ke své WiFi a ESP8266 se k ní pak bude automaticky připojovat.

### 4.1.6 Komunikace se serverem

Pro vzdálené ovládání bezpečnostního zařízení je nutná jeho komunikace se serverem. Tu zajišťuji pomocí HTTP GET a POST požadavků z ESP8266 na server.

#### Získávání hodnot

Získávání dat ze serveru řeším pomocí HTTP GET požadavku z ESP8266. Funkce getValues() se připojí k serveru a získá HTML stránku, která obsahuje JSON s daty. Následně se zbaví hlavičky stránky a pomocí knihovny ArduinoJson dekóduje JSON data. Ta se pak uloží do proměnných, se kterými lze dále pracovat (obrázek č. 10).


Obrázek č. 10 Ukázka kódu z funkce pro získání JSON dat ze serveru

#### Odesílání hodnot

Odesílání dat na server mi zajišťuje funkce postValues(). Ta zakóduje data do JSON výstupu, připojí se na server a pomocí HTTP POST požadavku tato data odešle (obrázek č. 11). Zbytek obstará samotná webová aplikace.


Obrázek č. 11 Ukázka kódu z funkce pro odesílání JSON dat na server

## 4.2 Webová aplikace

Při tvorbě webové aplikace mi značně usnadnil práci Nette Framework, který již obsahuje četná bezpečnostní opatření. Například pro přihlašování uživatelů tedy využívám funkce, které již Nette v základu má. Při řešení designu aplikace mi pomohl framework Bootstrap, díky kterému je uživatelské rozhraní plně responzivní. Důležitou částí aplikace je databázový systém MySQL, do kterého prostřednictvím Nette ukládám data, ke kterým pak můžu přistupovat.

### 4.2.1 Přihlášení

Do aplikace je nejprve vždy nutné se přihlásit pomocí uživatelského jména a hesla (obrázek č. 12).


Obrázek č. 12 Přihlašovací okno do webové aplikace

Po přihlášení se pomocí údajů v databázi rozhodne, zda se přihlásil běžný uživatel nebo administrátor. Na tom závisí, jaká práva bude daný uživatel v aplikaci mít.

### 4.2.2 Nastavení

Běžný uživatel může upravit své osobní údaje jako jméno nebo heslo (obrázek č. 13) a také může aktivovat nebo deaktivovat alarm.


Obrázek č. 13 Formulář pro změnu hesla

Administrátor může kromě již zmíněného také upravovat údaje ostatních uživatelů, popřípadě přidávat nové uživatele nebo mazat současné (obrázek č. 14).


Obrázek č. 14 Administrace uživatelů

Má právo také upravovat dobu do aktivace a dobu do spuštění alarmu (obrázek č. 15).


Obrázek č. 15 Nastavení bezpečnostního zařízení

### 4.2.3 Bezdrátová komunikace

Důležitým úkolem webové aplikace je také komunikace s hardwarovým zařízením. Ta je řešena pomocí REST API. Za účelem poskytování dat pro ESP8266 jsem vytvořil funkci, která získá data z databáze a vytvoří z nich JSON výstup. Ten si potom snadno stáhne a dekóduje samotné zařízení pomocí HTTP GET požadavku. Získávání dat z ESP8266 jsem vyřešil pomocí HTTP POST požadavku ze zařízení, ve kterém posílám JSON výstup. Tato data pak v aplikaci zpracuji, JSON dekóduji a hodnoty uložím do databáze.

# 5 Výsledky řešení

## 5.1 Podoba hardwarového zařízení

Bezpečnostní zařízení je v současné době plně funkční, po několika denním testování splňuje mé počáteční očekávání a všechny jeho funkce bez problému fungují. Z důvodu častých úprav je zařízení umístěno na dvou nepájivých polích. Do budoucna by bylo vhodné vytvořit pevný plošný spoj na poli pájivém, zejména kvůli křehkosti současného řešení. Systém jsem umístil do jednoduché krabičky s vyvrtanými otvory pro napájecí kabel a pro ultrazvukový senzor. Jak jsem již dříve v dokumentaci zmiňoval, napájení kabelem z elektrické sítě není u bezpečnostního systému vhodné, protože by případnému narušiteli stačilo vytrhnout napájecí kabel z elektrické zásuvky. Lepší by bylo napájet zařízení výkonnou baterií schovanou v krabičce, popřípadě systém umístit napevno do zdi a přímo připojit k elektrické síti.


Obrázek č. 16 Bezpečnostní zařízení ve vývoji

## 5.2 Podoba webové aplikace

Webová aplikace spolehlivě splňuje svůj účel, uživatelé se bez problému přihlásí a následně mohou v aplikaci dělat přesně to, co jim dovolují jejich uživatelská práva. Běžní uživatelé se proto nedostanou k administrátorským nastavením nebo k jiným nepřístupným částem aplikace. Administrátor naopak může kdykoliv měnit všechny údaje: své vlastní, údaje ostatních uživatelů a samozřejmě nastavení bezpečnostního zařízení. Aplikace je také plně responzivní, lze ji proto používat i na mobilních telefonech nebo tabletech. Do budoucna bych rád přidal více možností nastavení jako například automatickou aktivaci bezpečnostního systému v určité době a podobně.


Obrázek č. 18 Tlačítko pro aktivaci alarmu

Obrázek č. 17 Tlačítko pro deaktivaci alarmu

## 5.3 Bezdrátová komunikace

Komunikace mezi webovou aplikací a hardwarovým zařízením na principu REST API funguje spolehlivě. Pro bezpečnostní zařízení však není nejvhodnější, jak z hlediska bezpečnosti, tak samotné funkčnosti, jelikož je nezbytné zasílat ze zařízení požadavky na server v pravidelných časových intervalech a mezi těmito intervaly se zařízení nemá jak dozvědět o případných změnách v aplikaci (například o impulsu k aktivaci alarmu). Vhodnější by proto pro tento konkrétní případ bylo využití jiné technologie, například protokolu MQTT, který by zařízení se serverem spojil trvale a reagoval by pouze na změny. Rád bych také komunikaci lépe zabezpečil proti případným pokusům o narušení, například pomocí protokolu HTTPS.

# Závěr

Cílem projektu bylo vytvořit funkční bezpečnostní systém s možností ovládat jej na dálku prostřednictvím webové aplikace. Vytyčené cíle byly splněny, bezpečnostní zařízení i webová aplikace bez problému fungují. Při vývoji mě nicméně napadl nespočet možných změn, které by zařízení vylepšily, jako například napájení z baterie nebo lepší způsob komunikace mezi aplikací a zařízením. Na tato vylepšení mi již bohužel nestačil čas před termínem odevzdání práce, proto se jim budu věnovat později. Rád bych také přidal více možností nastavení do webové aplikace, jako například možnost automaticky aktivovat alarm v určitou dobu a podobně. Samotné součástky bych rád umístil na desku plošných spojů místo dvou nepájivých polí, čímž bych vyřešil problém s křehkostí celého zařízení.

# Seznam použitýCH INFORMAČNÍCH ZDROJů

[1] ESP8266 Quick Start Guide [online]. [cit. 2017-12-28]. Dostupné z: http://rancidbacon.com/files/kiwicon8/ESP8266_WiFi_Module_Quick_Start_Guide_v_1.0.4.pdf

[2] Logic Level Shifting [online]. [cit. 2017-12-28]. Dostupné z: http://www.instructables.com/id/A-Quick-Guide-on-Logic-Level-Shifting/

[3] ESP8266 Full Communication From Anywhere in the World [online]. In: 12. 12. 2015 [cit. 2017-12-28]. Dostupné z: https://www.youtube.com/watch?v=uWbLpMJ8jiA

[4] Nette autentifikace [online]. [cit. 2017-12-28]. Dostupné z: https://doc.nette.org/cs/2.4/quickstart/authentication

[5] Nette autentizace [online]. [cit. 2017-12-28]. Dostupné z: https://doc.nette.org/cs/2.4/access-control

[6] Nette Tracy [online]. [cit. 2017-12-28]. Dostupné z: https://tracy.nette.org/cs/

[7] Drahak REST API, chráněná komunikace [online]. [cit. 2017-12-28]. Dostupné z: https://www.itnetwork.cz/php/nette/diskuzni-forum-php-nette-framework/drahak-rest-api-chranena-komunikace-5767f69a2b12b

[8] JSON decode [online]. [cit. 2017-12-28]. Dostupné z: http://php.net/manual/en/function.json-decode.php

[9] ArduinoJson [online]. [cit. 2017-12-28]. Dostupné z: https://github.com/bblanchon/ArduinoJson

[10] ESP8266 Internet Controlled LED [online]. [cit. 2017-12-28]. Dostupné z: http://blog.nyl.io/esp8266-led-arduino/

[11] Arduino multitasking [online]. [cit. 2017-12-28]. Dostupné z: https://learn.adafruit.com/multi-tasking-the-arduino-part-1/using-millis-for-timing

[12] I2C Keypad [online]. [cit. 2017-12-28]. Dostupné z: https://www.hackster.io/venkatesh_rao/i2c-keypad-73a012

[13] Insert JSON into database using PHP REST [online]. In: 18. 1. 2016 [cit. 2017-12-28]. Dostupné z: https://www.youtube.com/watch?v=4QYt2Yqo5TA

[14] ESP8266 EEPROM [online]. [cit. 2017-12-28]. Dostupné z: https://circuits4you.com/2016/12/16/esp8266-internal-eeprom-arduino/

[15] Over the Air transfer [online]. [cit. 2017-12-28]. Dostupné z: https://randomnerdtutorials.com/esp8266-ota-updates-with-arduino-ide-over-the-air/

# Seznam příloh

č. 1 Fotodokumentace

Příloha č. 1: Fotodokumentace


První verze bezpečnostního zařízení složená z Arduino UNO a ESP8266-01


Detail na rezistorové pole sloužící k zapojení klávesnice přes jeden analogový pin, později nahrazené I2C sběrnicí


Výroba krabičky na bezpečnostní zařízení


Finální podoba bezpečnostního zařízení

Závěrečná studijní práce, Jakub Feret, IT4, 2017/2018

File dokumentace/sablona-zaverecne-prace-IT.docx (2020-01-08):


Závěrečná studijní práce

dokumentace

Auto na dálkové ovládání

Lukáš Baďura


Obor: | 18-20-M/01 INFORMAČNÍ TECHNOLOGIE se zaměřením na počítačové sítě a programování
Třída: Školní rok: | IT4 2019/2020

#### Poděkování

Děkuji panu učiteli Ing. Petru Grussmannovi za užitečné rady, vylepšení a konzultaci mého projektu. Mým spolužákům za pomoc a řešení společných problémů.

Prohlašuji, že jsem závěrečnou práci vypracoval samostatně a uvedl veškeré použité
informační zdroje.

Souhlasím, aby tato studijní práce byla použita k výukovým účelům na Střední průmyslové
a umělecké škole v Opavě, Praskova 399/8.

V Opavě 31. 12. 2019

podpis autora práce

ANOTACE

Cílem projektu bylo sestavení auta na dálkové ovládání z mobilní aplikace v Android Studiu pomocí WiFi. Hardwarovou část tvoří vývojová deska NodeMcu s čipem ESP8266. Zařízení za pomoci již zmíněného ESP8266 a modulu L298N řídí čtyři převodové motory. Mobilní aplikace posílá ESP hodnoty, pokud jsou vyhodnoceny jako „pravda“ je spuštěna příslušná funkce pro pohyb auta. Softwarová část auta je řešena v jazyce Arduino, který je kombinací jazyků C a C++.

Goal of the project was build a remote controlling car with mobile application in Android Studio which uses WiFi to communicate. Hardware part of the project is development board with chip ESP8266. Project uses ESP8266 and L298N module to control 4 geared motors. Mobile application sends values to ESP. If is value evaluated as „true“ the function for car direction controll is launched.

Klíčová slova

WiFi; dálkové ovládání; NodeMcu; Arduino; převodové motory; mobilní aplikace; motorový modul

# OBSAH

# Úvod

Text úvodu

- je povinný, nadpis neměňte,
- tato část práce obsahuje:
  - náhled do řešené problematiky, zdůvodnění volby problematiky,
  - předem definované cíle práce,
  - motivaci pro další čtení textu včetně stručného uvedení obsahu následujících kapitol
- rozsah - max. 1 strana

# 1 Teoretická a metodická východiska

Text první kapitoly

- Teoretická část (též metodologická) obsahuje dosavadní poznatky k danému problému, definici pojmu, formulaci hypotéz, výběr metod, které použijete, a důvody pro jejich použití.
- nadpis volte podle zaměření své práce – např.:
  - Zpracování zvuku na počítači
  - Tvorba elektronických kurzů v prostředí Moodle
  - Drupal 7 – tvorba modulů
  - LDAP a adresářové služby
- využívejte správných citací z odborné literatury, případně internetových zdrojů

# 2 Využité technologie

Text druhé kapitoly

- nástroje, přístroje, programy a jiné materiální prostředky, včetně zdůvodnění jejich výběru, použité při řešení zadaného úkolu
- informace o použitých technologiích by neměly mít charakter reklamy na daný výrobek, ale měly by přinášet objektivní technický popis použitých prostředků včetně zdůraznění a vysvětlení klíčových parametrů

# 3 Způsoby řešení a použité postupy

Text třetí kapitoly

- popis řešení úkolu včetně, použité postupy a jejich vysvětlení, způsoby testování funkčnosti, parametry výrobku (programu, hotového řešení), schémata, obrázky z tvorby a finálního provedení, výpočty, použité příkazy…

# 4 Výsledky řešení, výstupy, uživatelský manuál

Text čtvrté kapitoly

- výčet splněných a nesplněných cílů, obrázky (schémata, vzorce apod.) z finálního provedení, prokázání funkčnosti, výsledné parametry výrobku apod.
- podle zaměření a charakteru práce je třeba volit vhodný nadpis pro tuto kapitolu, je samozřejmě možné i rozdělení na více kapitol (např. Uživatelské rozhraní internetové aplikace; Administrace internetové aplikace…)

# Závěr

Text závěru

- povinná část,
- shrnuje výsledky, hodnotí splnění cíle práce, uvádí možnost uplatnění řešení v praxi a nastínění případných dalších budoucích vylepšení
- kapitola se nečísluje (stejné jako úvod)

# Seznam použitýCH INFORMAČNÍCH ZDROJů

[1] BOHMAN, Ludvík. Zákon o pojistné smlouvě. Praha: Linde Praha a. s., 2004. 381 s. ISBN80-7201-504-4

[2] DUCHÁČKOVÁ, Eva. Principy pojištění a pojišťovnictví. 3. aktualizované vydání. Praha: Ekopress 2009. 224 s. ISBN 978-80-86929-51-4

[3] KUBALA, Petr. Planetární dvojcata - Věda a technika (Český rozhlas) [online].
Č. 2000-2008, poslední revize 19. 3. 2008 [cit. 2008-03-20].
<http://www.rozhlas.cz/veda/vesmir/_zprava/435849>.

[4] KULDOVÁ, O., FLEISCHMANNOVÁ, E. Metodická příručka k technice administrativy a obchodní korespondence. 1.vyd. Praha: Fortuna 1998. 111 s.
ISBN 80-7168-574-7. Kapitola 6, Metody nácviku psaní hmatovou metodou,
s. 28-29.

[5] VLACH, J. JE Temelín a zásobování teplem. Energetika, 2001, roč. 51, č. 3, s. 84 -85. ISSN 0375-8842.

- musí zahrnovat všechny prameny, knihy, internetové odkazy a další studijní podklady, z nichž jsme čerpali;
- kapitola se nečísluje a zde končí číslování stránek práce;
- jednotlivé publikace se uvádějí v abecedním pořadí podle příjmení autorů a iniciál jeho jména, který se píše za čárkou;
- příjmení autora se píše velkými písmeny;
- název publikace se zvýrazňuje kurzívou;
- jestliže jsou uvedeni více než tři autoři, je možné vypsat hlavního autora s poznámkou „a kol.“(a kolektiv).

# Seznam příloh

č. 1 Titulní list

č. 2 Čestné prohlášení

č. 3 Poděkování

Nepovinná část – pokud nemáte žádné přílohy ke své práci, tuto část odstraňte!

- Přílohy se zařazují na konec práce.
- Jsou to texty, obrázky, grafy, tabulky, které by přímo v textu byly zbytečně detailní, ale mají být po ruce k dokreslení východisek i výsledku řešení.
- Jsou číslovány a v textu se na ně může odkazovat.
- Před první přílohu se umisťuje seznam příloh.
- Každá příloha je označena číslem - např. Tabulka č.. 1, Schéma č. 2, Obrázek č. 3.
- Každá tabulka by měla mít i vlastní název, který stručně vystihuje její obsah.
- (Tabulka č. 1 Zakázky stavebních prací v roce 2009-2010).
- Pokud je z tabulky vytvořen graf, umístíme jej na stejné stránce jako tabulku.

Příloha č. 1: Titulní list

Závěrečná studijní práce, Jméno Příjmení, IT4, 2016/2017

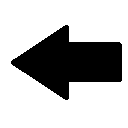
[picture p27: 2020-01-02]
grafika_aplikace/doleva.png

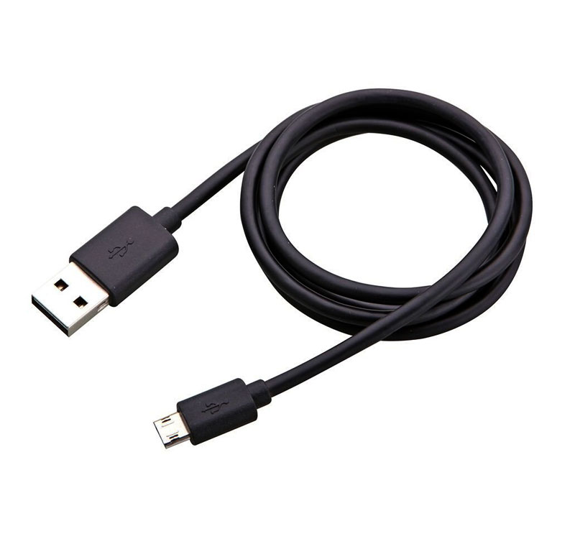
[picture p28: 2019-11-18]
Soucastky/Micro-USB-Cable.jpg

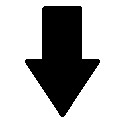
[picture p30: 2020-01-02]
grafika_aplikace/dolu.png

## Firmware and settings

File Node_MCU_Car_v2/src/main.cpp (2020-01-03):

#define ENA   14          // povoluje rychlost motoru doprava  na pinu GPIO14(D5)
#define ENB   12          // povoluje rychlost motoru doleva  na pinu GPIO12(D6)

#define IN_1  15          // L298N in1 motor doprava na pinu  GPIO15(D8)
#define IN_2  13          // L298N in2 motor doprava na pinu  GPIO13(D7)
#define IN_3  2           // L298N in3 motor doleva na pinu GPIO2(D4)
#define IN_4  0           // L298N in4 motor doleva na pinu GPIO0(D3)

#include <ESP8266WiFi.h>
#include <WiFiClient.h> 
#include <ESP8266WebServer.h>

int rychlost = 800;         // 400 - 1023.
int koeficient = 3;
int cislo;  // Proměnná do které se uloží hodnota poslaná aplikací ve stringu a následném převedení funkcí toInt().

const char* ssid = "Auticko";

ESP8266WebServer server(80); 

void HTTP_handleRoot(void) {

  if (server.hasArg("State")) {   //Když program příjme hodnotu state, uloží se do proměnné číslo převedený string na int.
  cislo = server.arg("State").toInt();
    
  }
  server.send ( 200, "text/html", "" );
  delay(1);
}


void setup() {  //Nastavení pinů
 
 pinMode(ENA, OUTPUT);
 pinMode(ENB, OUTPUT);  

 pinMode(IN_1, OUTPUT);
 pinMode(IN_2, OUTPUT);
 pinMode(IN_3, OUTPUT);
 pinMode(IN_4, OUTPUT); 
  
  Serial.begin(115200); //Nastavení komunikačního portu na 115200
  
// Připojení k wifi

  WiFi.mode(WIFI_AP);
  WiFi.softAP(ssid);

  IPAddress mojeIP = WiFi.softAPIP(); //Výpis IP adresy pro zadání do mobilní aplikace.
  Serial.print("IP adresa je: ");
  Serial.println(mojeIP);
 
 // Zapojení web serveru 
     server.on ( "/", HTTP_handleRoot );
     server.onNotFound ( HTTP_handleRoot );
     server.begin();    
}

//Fuknce pro řízení auta

void dopredu(){ 

      digitalWrite(IN_1, LOW);
      digitalWrite(IN_2, HIGH);
      analogWrite(ENA, rychlost);

      digitalWrite(IN_3, LOW);
      digitalWrite(IN_4, HIGH);
      analogWrite(ENB, rychlost);
  }

void dozadu(){ 

      digitalWrite(IN_1, HIGH);
      digitalWrite(IN_2, LOW);
      analogWrite(ENA, rychlost);

      digitalWrite(IN_3, HIGH);
      digitalWrite(IN_4, LOW);
      analogWrite(ENB, rychlost);
  }

void doprava(){ 

      digitalWrite(IN_1, HIGH);
      digitalWrite(IN_2, LOW);
      analogWrite(ENA, rychlost);

      digitalWrite(IN_3, LOW);
      digitalWrite(IN_4, HIGH);
      analogWrite(ENB, rychlost);
  }

void doleva(){

      digitalWrite(IN_1, LOW);
      digitalWrite(IN_2, HIGH);
      analogWrite(ENA, rychlost);

      digitalWrite(IN_3, HIGH);
      digitalWrite(IN_4, LOW);
      analogWrite(ENB, rychlost);
  }

void stop(){  

      digitalWrite(IN_1, LOW);
      digitalWrite(IN_2, LOW);
      analogWrite(ENA, rychlost);

      digitalWrite(IN_3, LOW);
      digitalWrite(IN_4, LOW);
      analogWrite(ENB, rychlost);
 }

void loop() {
    server.handleClient();
      //Porovnávání hodnot v proměnné číslo ve switchi, pokud se vyhodnotí jako pravda, je vyvolána příslušná funkce. 
    
    switch(cislo){
      case 1:
        dopredu();
      break;
      case 4:
         dozadu();
      break;
      case 3:
          doleva();
      break;
      case 2:
        doprava();
      break;
      case 5:
        stop();
      break;
    }
}

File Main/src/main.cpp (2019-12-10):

#define ENA   14          // Enable/speed motors Right        GPIO14(D5)
#define ENB   12          // Enable/speed motors Left         GPIO12(D6)
#define IN_1  15          // L298N in1 motors Right           GPIO15(D8)
#define IN_2  13          // L298N in2 motors Right           GPIO13(D7)
#define IN_3  2           // L298N in3 motors Left            GPIO2(D4)
#define IN_4  0           // L298N in4 motors Left            GPIO0(D3)

#include <ESP8266WiFi.h>
#include <WiFiClient.h> 
#include <ESP8266WebServer.h>

String command;             //String to store app command state.
int speedCar = 800;         // 400 - 1023.
int speed_Coeff = 3;

const char* ssid = "NodeMCU Car";
ESP8266WebServer server(80);

void HTTP_handleRoot(void) {

if( server.hasArg("State") ){
       Serial.println(server.arg("State"));
  }
  server.send ( 200, "text/html", "" );
  delay(1);
}

void setup() {
 
 pinMode(ENA, OUTPUT);
 pinMode(ENB, OUTPUT);  
 pinMode(IN_1, OUTPUT);
 pinMode(IN_2, OUTPUT);
 pinMode(IN_3, OUTPUT);
 pinMode(IN_4, OUTPUT); 
  
  Serial.begin(115200);
  
// Connecting WiFi

  WiFi.mode(WIFI_AP);
  WiFi.softAP(ssid);

  IPAddress myIP = WiFi.softAPIP();
  Serial.print("AP IP address: ");
  Serial.println(myIP);
 
 // Starting WEB-server 
     server.on ( "/", HTTP_handleRoot );
     server.onNotFound ( HTTP_handleRoot );
     server.begin();    
}

void goAhead(){ 

      digitalWrite(IN_1, LOW);
      digitalWrite(IN_2, HIGH);
      analogWrite(ENA, speedCar);

      digitalWrite(IN_3, LOW);
      digitalWrite(IN_4, HIGH);
      analogWrite(ENB, speedCar);
  }

void goBack(){ 

      digitalWrite(IN_1, HIGH);
      digitalWrite(IN_2, LOW);
      analogWrite(ENA, speedCar);

      digitalWrite(IN_3, HIGH);
      digitalWrite(IN_4, LOW);
      analogWrite(ENB, speedCar);
  }

void goRight(){ 

      digitalWrite(IN_1, HIGH);
      digitalWrite(IN_2, LOW);
      analogWrite(ENA, speedCar);

      digitalWrite(IN_3, LOW);
      digitalWrite(IN_4, HIGH);
      analogWrite(ENB, speedCar);
  }

void goLeft(){

      digitalWrite(IN_1, LOW);
      digitalWrite(IN_2, HIGH);
      analogWrite(ENA, speedCar);

      digitalWrite(IN_3, HIGH);
      digitalWrite(IN_4, LOW);
      analogWrite(ENB, speedCar);
  }

void goAheadRight(){
      
      digitalWrite(IN_1, LOW);
      digitalWrite(IN_2, HIGH);
      analogWrite(ENA, speedCar/speed_Coeff);
 
      digitalWrite(IN_3, LOW);
      digitalWrite(IN_4, HIGH);
      analogWrite(ENB, speedCar);
   }

void goAheadLeft(){
      
      digitalWrite(IN_1, LOW);
      digitalWrite(IN_2, HIGH);
      analogWrite(ENA, speedCar);

      digitalWrite(IN_3, LOW);
      digitalWrite(IN_4, HIGH);
      analogWrite(ENB, speedCar/speed_Coeff);
  }

void goBackRight(){ 

      digitalWrite(IN_1, HIGH);
      digitalWrite(IN_2, LOW);
      analogWrite(ENA, speedCar/speed_Coeff);

      digitalWrite(IN_3, HIGH);
      digitalWrite(IN_4, LOW);
      analogWrite(ENB, speedCar);
  }

void goBackLeft(){ 

      digitalWrite(IN_1, HIGH);
      digitalWrite(IN_2, LOW);
      analogWrite(ENA, speedCar);

      digitalWrite(IN_3, HIGH);
      digitalWrite(IN_4, LOW);
      analogWrite(ENB, speedCar/speed_Coeff);
  }

int digit_to_int(char d)
{
 char str[2];

 str[0] = d;
 str[1] = '\0';
 return (int) strtol(str, NULL, 10);
}


void stopRobot(){  

      digitalWrite(IN_1, LOW);
      digitalWrite(IN_2, LOW);
      analogWrite(ENA, speedCar);

      digitalWrite(IN_3, LOW);
      digitalWrite(IN_4, LOW);
      analogWrite(ENB, speedCar);
 }

void loop() {
    server.handleClient();
    
      command = server.arg("State");

      int vysledek = command.toInt();
      println(vysledek);
      switch(vysledek){
        case ̈́int('B'):
          goAhead();
        break;


      }

      if (command == "F") goAhead();
      else if (command == int("B")) goBack();
      else if (command == "L") goLeft();
      else if (command == "R") goRight();
      else if (command == "I") goAheadRight();
      else if (command == "G") goAheadLeft();
      else if (command == "J") goBackRight();
      else if (command == "H") goBackLeft();
      else if (command == "0") speedCar = 400;
      else if (command == "1") speedCar = 470;
      else if (command == "2") speedCar = 540;
      else if (command == "3") speedCar = 610;
      else if (command == "4") speedCar = 680;
      else if (command == "5") speedCar = 750;
      else if (command == "6") speedCar = 820;
      else if (command == "7") speedCar = 890;
      else if (command == "8") speedCar = 960;
      else if (command == "9") speedCar = 1023;
      else if (command == "S") stopRobot();

      
}

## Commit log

2019-11-05 Create roztoceni_kolecka
    Roztočení jednoho motoru s kolečkem pomocí L298N a ESP8266.
2019-12-19 Add files via upload
    Optimalizovaný kód, nahrazení ifů za switch pro lepší funkčnost a přehlednost. Konvertace stringů z aplikace na int pro použití ve switchi.
